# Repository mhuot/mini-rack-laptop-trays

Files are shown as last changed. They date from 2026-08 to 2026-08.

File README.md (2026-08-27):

# Mini-Rack Laptop Trays

1U sliding laptop trays for 10-inch mini racks, with an actively cooled, ducted rear exhaust — designed for a MacBook Pro 14" and a Surface Laptop 13.8" living in a GeeekPi/DeskPi RackMate-style 4U cabinet.

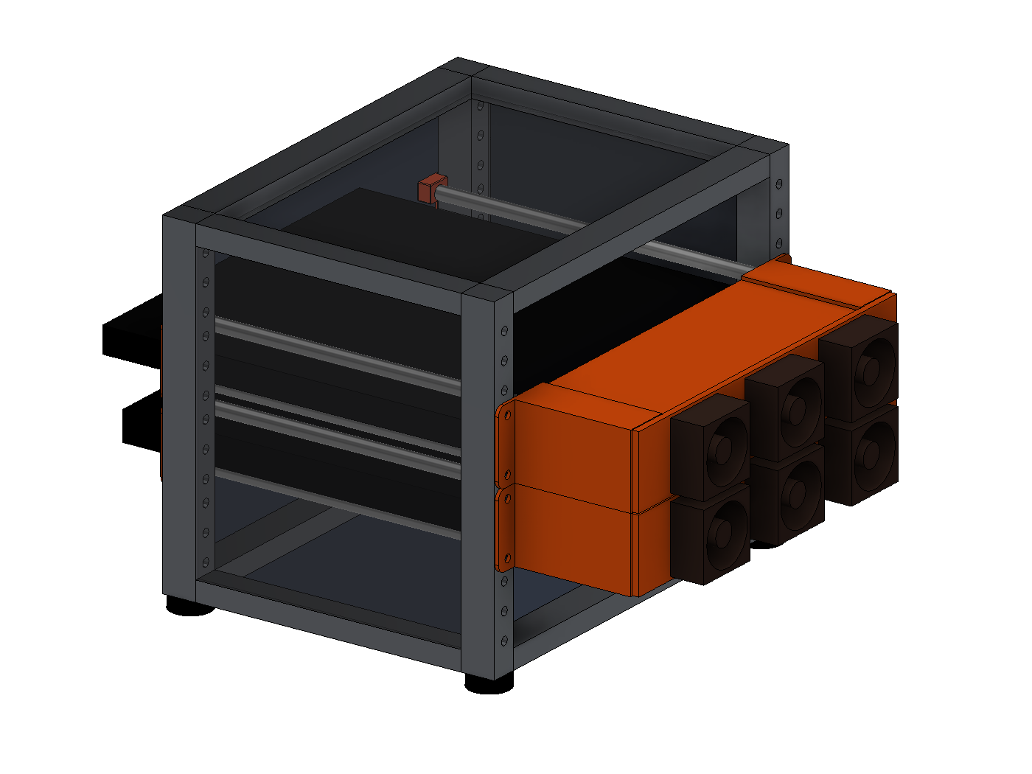
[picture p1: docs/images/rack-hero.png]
Rack mockup with both laptops


Each laptop slides in and out like a drawer on four 8 mm smooth rods, held by 3D-printed ears on the front and rear rack rails. A printed fan plate with three 40 mm Noctua fans bolts onto the rear ears and pulls air across the top and bottom of the laptop, exhausting out the back — all within a single rack unit.

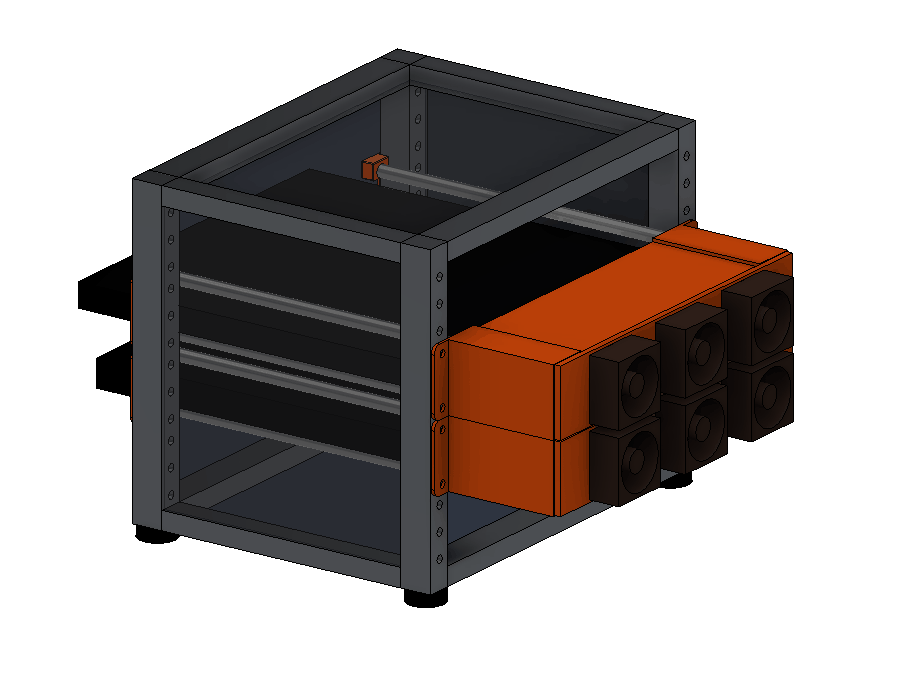
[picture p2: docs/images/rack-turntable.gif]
Turntable spin of the full rack


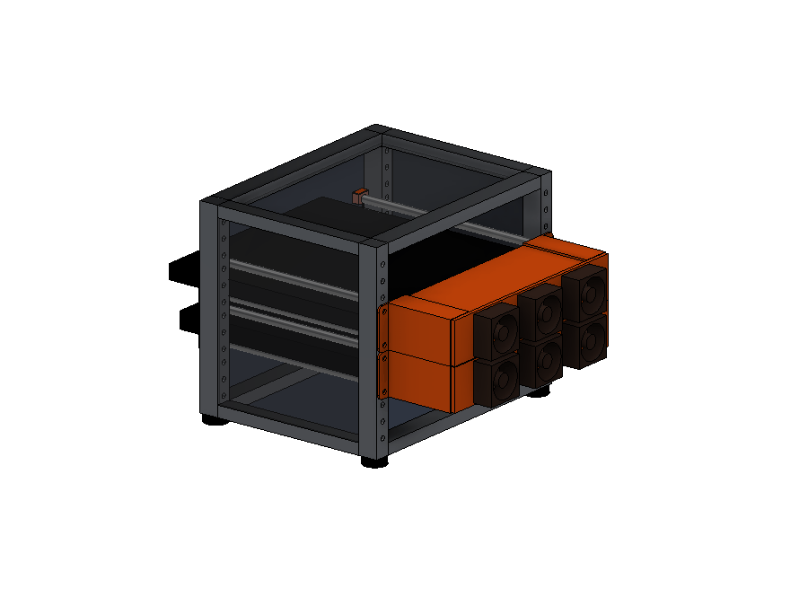
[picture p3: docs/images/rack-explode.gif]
Exploded view of one tray flying apart and back together


Every printed part in the bill of materials is in there, except the fan opening plug — that one only exists if you run two fans instead of three, and this shows three. Fasteners are not modelled.

Want to spin it yourself? **[Open the interactive 3D viewer](https://mhuot.github.io/mini-rack-laptop-trays/)** — full color, drag to orbit, scroll to zoom. GitHub also renders **[docs/rack-mockup.stl](docs/rack-mockup.stl)** with its built-in STL viewer. (Both are visual mockups, not print files — the printable STLs live in [`exports/`](exports/). Printed parts are shown in orange; print in whatever color you like.)

## How it works

| | |
|---|---|
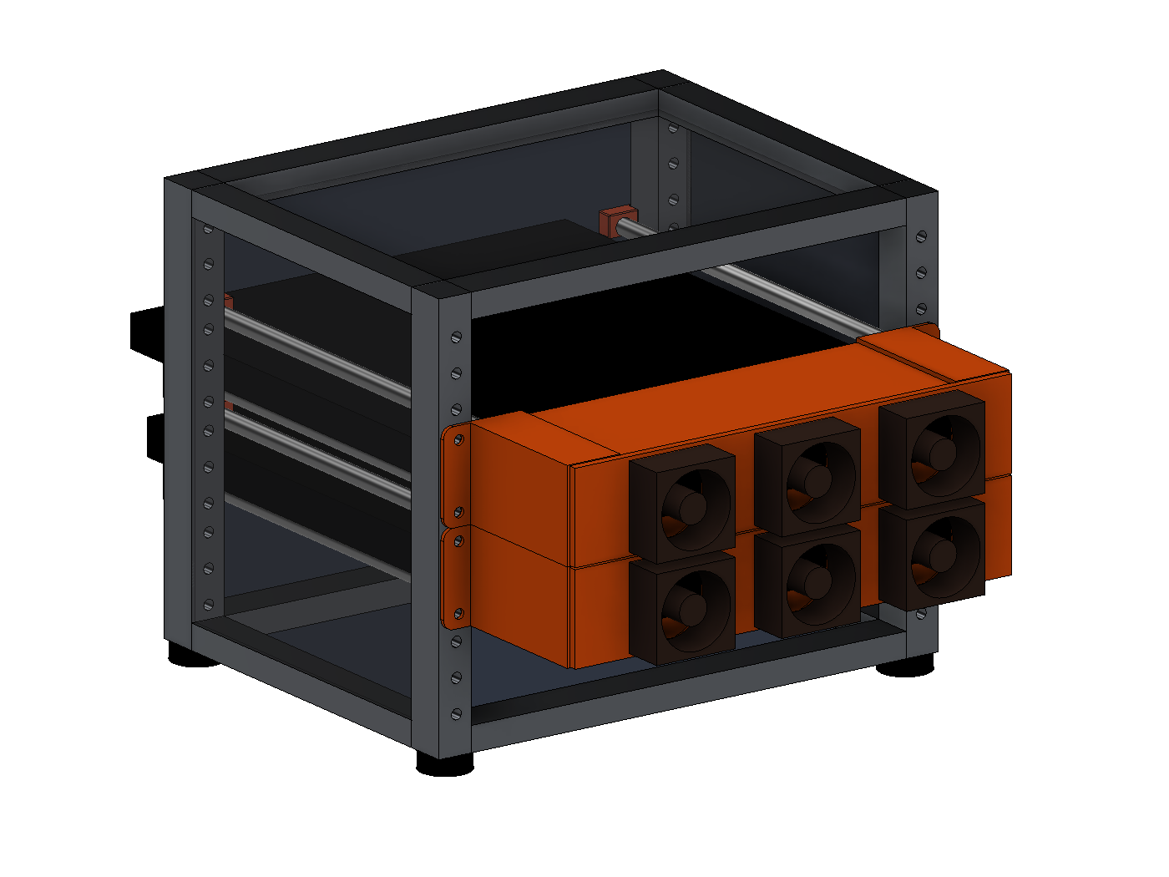
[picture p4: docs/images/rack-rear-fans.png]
Rear fan plates and ducts
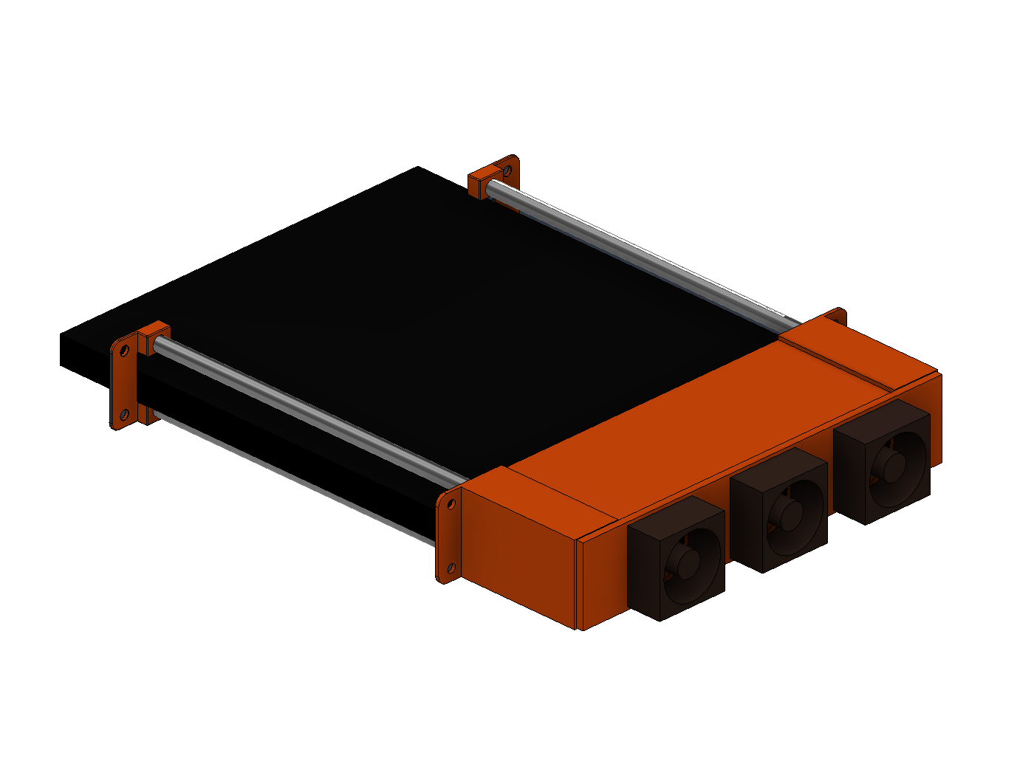
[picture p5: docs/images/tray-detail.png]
Single tray assembly
|  |  |

- **Front and rear ears** print in mirrored pairs and bolt to the rack rails with standard rack screws. Each ear carries two 8 mm smooth-rod positions, spaced to leave a 24 mm gap — the laptop slides between the rod pairs and rests on the lower rods.
- **The rear ears extend 72 mm out the back of the rack**, so the laptop's rear edge sits behind the rear rail and stops against the ears' back plates **65 mm in**. The rod bores run that same 65 mm, so they are blind — the back plate is their floor. The 243 mm rods reach 41 mm in and leave 24 mm of bore empty; a 267 mm rod would bottom out on the plate and be positively located. A MacBook Pro 14 noses 47.6 mm out the front; the Surface Laptop 13.8, 36.0 mm. The 7 mm left between that stop and the fan plate is the duct exit — the gap the air turns through on its way into the fans.
- **The fan plate** screws into heat-set inserts in the rear ears' back plates. Three Noctua NF-A4x20 5V fans (40 mm fits upright inside the 44.45 mm rack unit) exhaust rearward, at x = 0 and ±63.55 — the centroids of three equal zones across the duct, so each draws its own third of it. Two 2.2 mm duct panels close the top and bottom of the rear overhang, and the rear ears carry a 2 mm outboard side wall closing their side windows — so the fans can only draw air from inside the rack, sweeping the lid and the underside of the chassis on the way through.
- **Fan wiring** runs along the rear face of the plate, held clear of the blades by zip ties through the slot pairs between the fan bodies. The outboard pair is strain relief where the bundle leaves for the USB supply. Splices belong outside the rack, near the power source, not pocketed into a 4 mm plate.
- Laptops run clamshell; all cables exit at the front (orient the Surface with its USB-C edge forward).
- The RackMate-style cabinet has closed acrylic sides and top, so the front opening is the only intake: the fans drive true front-to-back flow through the slot, and the hinge-side exhaust is entrained in the same rearward stream. No side baffles needed.

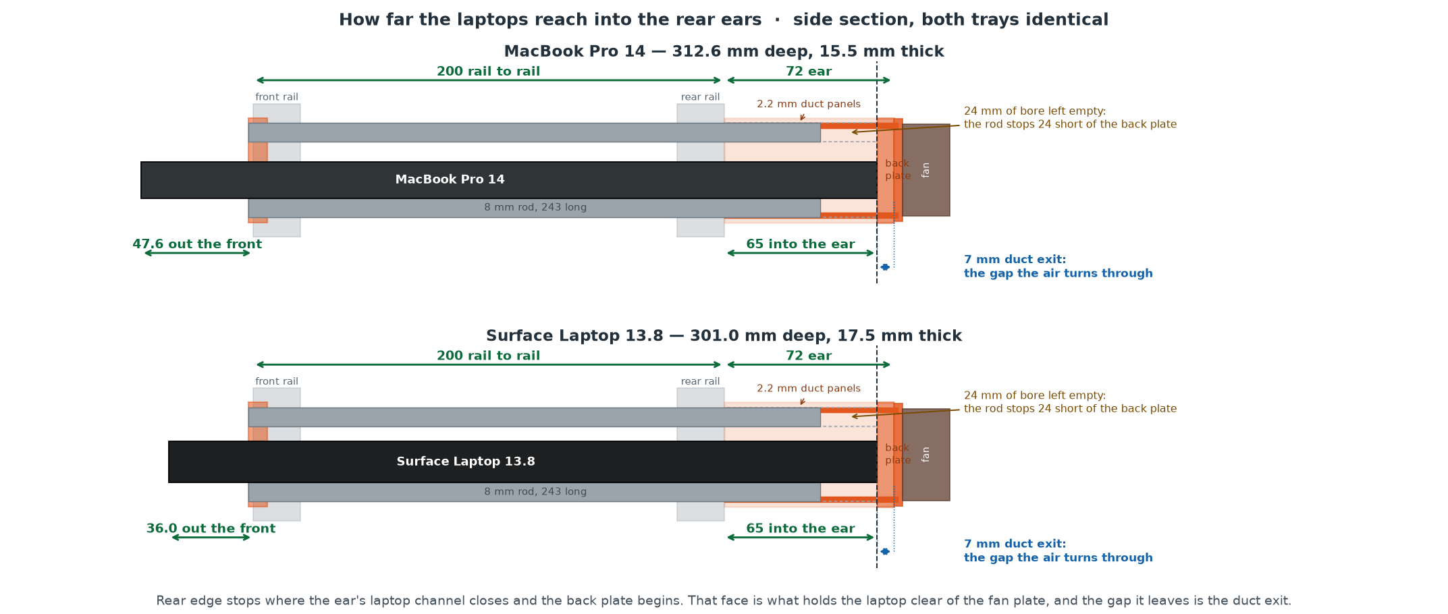
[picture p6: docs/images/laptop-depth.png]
Side section showing how far each laptop reaches into the rear ears


## Compatibility

Designed around a rack with 236.525 mm rail-hole span and 200 mm rail-to-rail depth ([GeeekPi 4U 10-inch cabinet / DeskPi RackMate T0](https://www.amazon.com/dp/B0DPGZPTPP); see the [mini-rack project](https://mini-rack.jeffgeerling.com/) for the ecosystem).

| Laptop | Dimensions (mm) | Fit |
|---|---|---|
| MacBook Pro 14 (M-series) | 312.6 × 221.2 × 15.5 | ✅ designed for |
| Surface Laptop 7th Ed. 13.8" (Intel) | 301 × 220 × 17.5 | ✅ same parts, unchanged |

Anything ≤ 222 mm deep and ≤ ~20 mm thick that can hang its side edges on rods 205.6 mm apart should work.

## Bill of materials (per tray)

**Printed parts** (PETG recommended — parts live next to a warm laptop):

| Part | Qty | Notes |
|---|---|---|
| Front Ear (`exports/front_ear.stl`) | 2 | mirror one in the slicer |
| Rear Ear v2 (`exports/rear_ear_v2.stl`) | 2 | mirror one; bosses take M3 heat-set inserts |
| Rear Fan Plate (`exports/rear_fan_plate.stl`) | 1 | flat 4 mm slab, ~45 min |
| Duct panel (`exports/duct_panel.stl`) | 2 | flat 2.2 mm sheets, 194.4 × 74; slide into the ears' duct rails |
| Fan opening plug (`exports/fan_plug.stl`) | 0–1 | only if starting with two fans — see below |

**Ready-made print plates**, arranged for a 250 × 220 bed and mirrored where needed. Regenerate with `scripts/build_print_plate.py`.

- `exports/print_plate_ears_heatset.3mf` (also `_selftap` / `_nuttrap`) — both rear ears, both front ears, two fan plugs. Print once.
- `exports/print_plate_ducted_fan_plate.3mf` — the one-piece alternative, if you want it instead of the plate-plus-panels.
- `exports/print_plate_duct_panels.3mf` and `exports/print_plate_fan_plate.3mf` — the duct set, split across two plates. This is what you reprint when you change the fan layout.

The duct is two plates rather than one because together the three parts fill the bed corner to corner, which put a panel corner 14 mm from the left edge and 8 mm from the front — and that corner is where first layers fail. Split, each plate centres with at least 20 mm clear on every side, brim included.

The ears also fit a Prusa Mini, so they can go on a second printer while the duct set runs: `exports/print_plate_ears_heatset_mini.3mf`. Neither duct plate can — the panels are 194 mm and the fan plate 222 mm, both past a 180 mm bed. Pass `--bed mini` to the generator for other variants.

The duct is modular on purpose. The two panels slide into duct rails on the rear ears and are trapped by the fan plate, so the duct stays with the rack when the plate comes off. Changing fan count or spacing means reprinting a flat slab in under an hour instead of a six-hour part that is mostly duct wall.

Those duct rails reach 10 mm inboard from each ear, into the dead space above and below the laptop, and carry a 2.4 mm slot between 2 mm walls. That holds a panel over 12 mm of its width rather than the 2 mm a pocket in the ear face managed on its own, and it does it without making the panel any bigger — the rails add material rather than hollowing the ear out, so the rod bores are untouched and the part still prints with no overhangs.

The duct rails only grip 10 mm at each end, though, which left 170 mm of free sheet whose rear edge had nothing holding it against the fan plate. So the plate carries a 2 mm-deep capture groove on each panel line and the panels run 74 mm — 72 of duct plus 2 into the groove. That laps the joint instead of butting it, and pulls the rear edge flat at the same time. Along the panel line each fan opening is only about 8.6 mm wide, so roughly 76% of the panel edge lands in solid groove and the rest opens into a fan opening, which is where the air is going anyway.

Panels are 2.2 mm rather than 2.0 for the same reason a loose hinge rattles: 2.0 in a 2.4 slot leaves 0.4 mm of free play, and a 37 g sheet with that much room next to the fans will buzz. 2.2 is eleven layers at 0.2 mm and halves the gap to a normal sliding fit.

`scripts/check_rear_assembly.py` fits the exported STLs together and checks both of these — every pair intersected exactly for interference, then a flood fill of the air in a cross-section to see whether the duct reaches ambient. It currently reports no interference, and a seal with each panel resting against either wall of its slot.

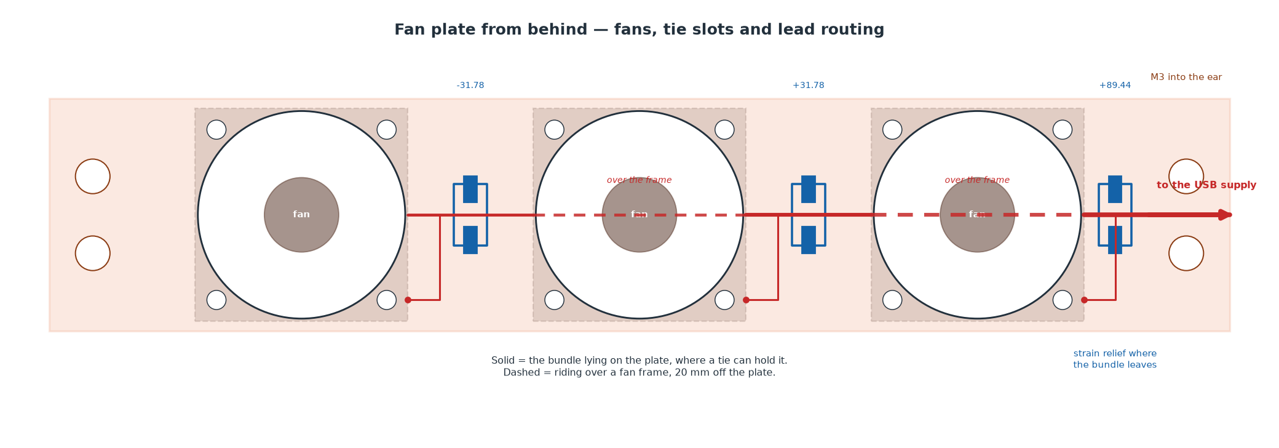
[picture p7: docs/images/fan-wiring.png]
Fan plate from behind, showing the fans, tie slots and lead routing


### Why three fans

Three is where the fan openings stop being the restriction. The duct's own free
area is about 3880 mm² with a MacBook in it and 3498 with the thicker Surface;
three Ø39 openings are 3584 mm². Two would be 2389 — throttling the duct to 62%
and leaving a 47.7 mm fan-free span across the middle of the laptop. Four was
4778, comfortably past the crossover, buying noise rather than air. Three also
draws 0.3 A, so a tray still runs off any USB port.

Positions are the centroids of three equal-width zones, so no part of the duct
is more than 31.8 mm from a fan — against 47.7 mm with two.

### The one-piece alternative

`exports/ducted_fan_plate.stl` is the fan plate with the duct walls grown onto
it: one part instead of three, and no joint to seal because there isn't one.
Its walls are 194.44 mm wide, the same as the separate panels, so they slide
into the same duct rails.

It costs you the thing the modular duct was built for. The fan count is fixed
in the geometry, and the walls print as two 2.2 mm fins standing 72 mm off the
plate, which is slower and more delicate than two flat sheets. Print it
plate-down so the first layer is the full solid rectangle.

No heat-set inserts on hand? Two alternatives, same fan plate and M3 × 8 screws either way:

- **Nut-trap** (`exports/rear_ear_v2_nuttrap.stl`) — a slightly taller rib with side-loading slots that capture standard **M3 hex nuts** (a DIN 562 square nut fits the same slot). Metal threads, unlimited assembly cycles, hardware you already have. The fan plate sits 2 mm further back (~98 mm total behind the rear rail).
- **Self-tap** (`exports/rear_ear_v2_selftap.stl`) — Ø2.5 pilot holes the M3 screws thread directly into the plastic. Simplest, but good for only about a dozen assembly cycles.

The insert version remains the most compact and the nicest to work on.

A note on all three, because it is not obvious from looking at them: the ear prints standing on its rail flange, so the back plate starts as a bridge across the open duct and the insert pocket sits directly above it. Whatever floor is left under a pocket is made of the first bridged layers, with nothing on top to pull them flat — get it too thin and the bottom of the pocket comes out rough. The heat-set pocket is 3.2 mm deep on a 3.8 mm floor; the self-tap and nut-trap variants keep 1.5 mm on a thinner plate.

**Hardware:**

| Item | Qty | Notes |
|---|---|---|
| 8 mm smooth rod, 243 mm | 4 | see [Smooth rods](#smooth-rods) |
| [Noctua NF-A4x20 5V](https://www.amazon.com/Noctua-NF-A4x20-5V-3-Pin-Premium/dp/B072Q3CMRW) | 2–3 | ships with OmniJoin + fan screws |
| [M3 × 3 mm heat-set inserts (short)](https://cnckitchenus.store/products/heat-set-insert-m3-x-3-short-version-100-pieces) | 4 | e.g. CNC Kitchen; Ø4.0 × 3.2 pockets (skip for the self-tap ear variant) |
| M3 × 8 socket-head screws | 4 | |
| M3 hex nuts | 4 | nut-trap ear variant only |
| Rack screws | 8 | per your rack's rail standard |
| Spare USB-A cable to sacrifice | 1 per tray | spliced with the included OmniJoin set — see [Wiring](#wiring-the-fans) |
| Noctua NA-SYC1 chromax Y-cables | optional | [set of three](https://www.amazon.com/Noctua-NA-SYC1-black-NA-SYC1-chromax-Black-y-Cables/dp/B076542HBN) tidies one tray's junction |

## Wiring the fans

The NF-A4x20 5V draws 0.1 A max ([0.5 W, spec](https://www.noctua.at/en/products/nf-a4x20-5v/specifications)), so a full tray of four is 0.4 A worst case — inside the 0.5 A budget of any USB 2.0 port. Both trays on one port is 0.8 A, which wants a USB 3 port (0.9 A) or a 5 V / 1 A phone charger.

The box gives you everything except the USB end: each fan ships with a 30 cm extension and Noctua's OmniJoin splice set (solderless 3M connectors). No USB adapter is included, and **avoid generic "USB fan adapter" cables — most contain a 5 V→12 V boost converter that will kill a 5 V fan.** A 5 V Noctua must never see 12 V.

Per tray:

1. Sacrifice any USB-A cable. Cut off the device end, strip the jacket, keep the **red (+5 V)** and **black (GND)** conductors, and insulate the data pair (green/white) out of the way.
2. Join all three fans' +5 V leads to USB red and all three GND leads to USB black with the OmniJoin connectors (identify the fan leads from the OmniJoin instruction leaflet — Noctua's cables are all-black, the leaflet is the pinout). Leave each fan's tach lead unconnected and insulated; nothing reads it.
3. Route the bundle along the top duct panel, down the inside of the rear post, and zip-tie it with a service loop generous enough that the fan plate can be unscrewed without unplugging anything.
4. Plug in and confirm all four spin before sliding the laptop in.

If you'd rather not splice three joints, two [NA-SYC1 Y-cables](https://www.amazon.com/Noctua-NA-SYC1-black-NA-SYC1-chromax-Black-y-Cables/dp/B076542HBN) merge the three fans to a single 3-pin lead first, leaving one splice to the USB cable. Passive wiring, fine at 5 V.

**Two fans or three?** Rough math says two fans per tray move enough air for typical clamshell loads (~14 °C air rise carrying 40 W); three is what the duct can actually swallow — see [Why three fans](#why-three-fans). The plate has three openings either way, and an empty opening would let the running fans pull backflow, so if you start with two, print a plug and press it into the unused opening from the rear (duct suction seats it tighter). Use the two outer positions and plug the centre. To upgrade later, drive an M3 screw two turns into the plug's center pilot, pull it, and add the third fan — no reprint. The print plates include two plugs.

## Smooth rods

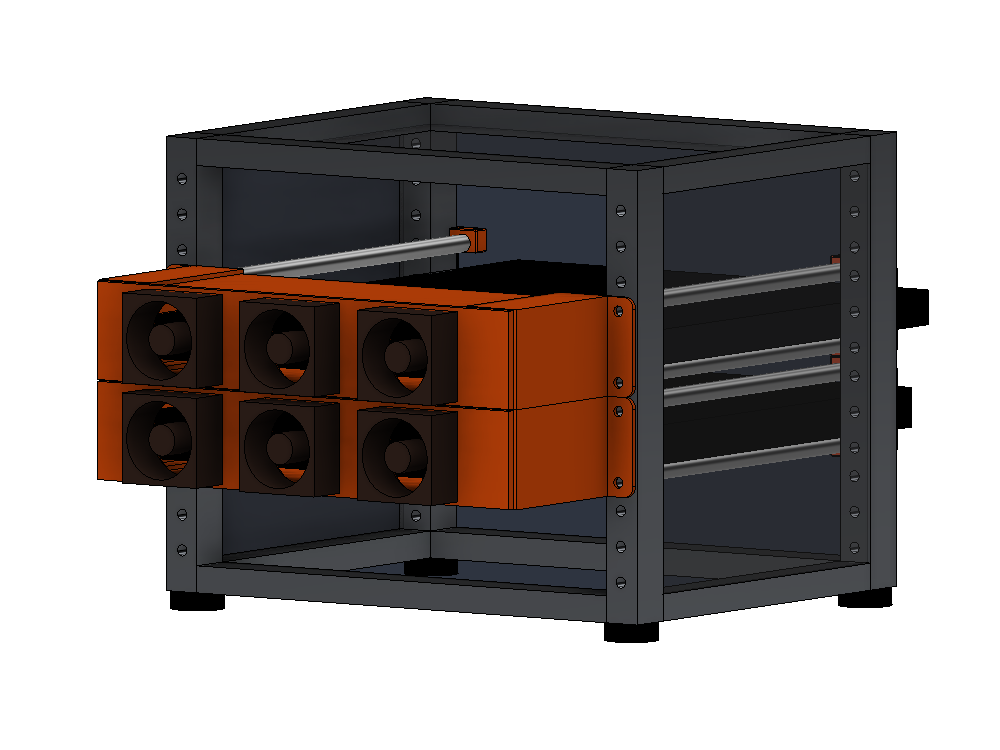
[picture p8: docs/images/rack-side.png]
Side view: rod runs and laptop overhang


Any 8 mm smooth rod works (hardened steel or stainless linear rod is ideal — it's what the renders show). The rods are just long enough to connect the front and rear ears — they do **not** extend past the front:

- **Cut all four rods to 243 mm** (the as-built length). That runs from flush with the front ear's face, through the 200 mm rack, and ~40 mm into the rear ears' bores — plenty of engagement without needing to bottom out against the rear back plates.
- The front ears straddle the front rail: only their thin 2 mm face plate (with the recessed screw heads) sits on the rail's front face, while the rod blocks pass through the rack opening behind it. The front of the rack stays essentially flush — nothing pokes forward but the laptops.
- The laptop's front overhang (MacBook Pro 14: ~45 mm, Surface 13.8: ~33 mm) is cantilevered past the front ears — the chassis is more than stiff enough for this.
- Deburr and lightly chamfer the ends so they slide into the printed bores without shaving them. The 8.0 mm fit is snug — no retention hardware needed, and the fan plate closes off the rear.

## Assembly

1. Print the parts; heat-set the four inserts into the rear ear bosses.
2. Mount front ears to the front rails, rear ears to the rear rails (rear ears point out the back of the rack).
3. Slide the four rods through the front ears into the rear ears' sockets.
4. Screw the fans to the rear face of the fan plate (labels facing back — they exhaust rearward), then drive the M3 screws through the plate's counterbored tabs into the ear inserts.
5. Wire the fans per [Wiring](#wiring-the-fans), confirm they spin, and slide the laptop in, lid closed, cables at the front.

Total stack behind the rear rail is ~96 mm (ears 69 + pads 3 + plate 4 + fans 20) — leave that much clearance behind the rack.

## CAD

Models are built in Fusion 360, driven by the Python scripts in [`scripts/`](scripts/) (run inside Fusion — e.g. via a Fusion MCP add-in, or paste into a Fusion script). Each script is parametric through the constants at the top and regenerates its part from scratch:

- [`build_rear_ear_v2.py`](scripts/build_rear_ear_v2.py) — copies the proven rear ear bodies and adds the insert bosses
- [`export_front_ear.py`](scripts/export_front_ear.py) — exports the front ear with a slicer-friendly tangency relief
- [`build_print_plate.py`](scripts/build_print_plate.py) — assembles the one-tray 3MF print plates from the STLs
- [`build_rear_fan_plate.py`](scripts/build_rear_fan_plate.py) — the fan plate, with the wiring tie slots
- [`build_duct_panel.py`](scripts/build_duct_panel.py) — the duct panels
- [`build_fan_plug.py`](scripts/build_fan_plug.py) — the blanking plug for unused fan openings
- [`build_rack_mockup.py`](scripts/build_rack_mockup.py) — the full-rack mockup used for the renders on this page
- [`add_duct_rails.py`](scripts/add_duct_rails.py) — adds the duct rails to the parametric rear ear
- [`fix_insert_pockets.py`](scripts/fix_insert_pockets.py) — cuts the heat-set pockets as one explicit feature

And three that run locally rather than inside Fusion:

- [`check_rear_assembly.py`](scripts/check_rear_assembly.py) — fits the rear parts together and checks for interference and air leaks
- [`whiten_renders.py`](scripts/whiten_renders.py) — flattens Fusion's viewport gradient to white in the exported renders
- [`check_terminology.py`](scripts/check_terminology.py) — every part has one name; this fails if a retired one creeps back in. Standard library only, so it just runs.

Fusion API note: all API lengths are centimeters; the scripts define `MM = 0.1` and work in millimeters throughout.

Every printable part also ships as standalone CAD in [`cad/`](cad/) — a STEP and a Fusion archive (`.f3d`) per part, current revision, importable into any CAD package. The original parametric ear and reference-body designs live in the Fusion archives (`*.f3d`) at the repo root.

## License

[MIT](LICENSE) — scripts, models, and STLs alike. Attribution appreciated but not required.

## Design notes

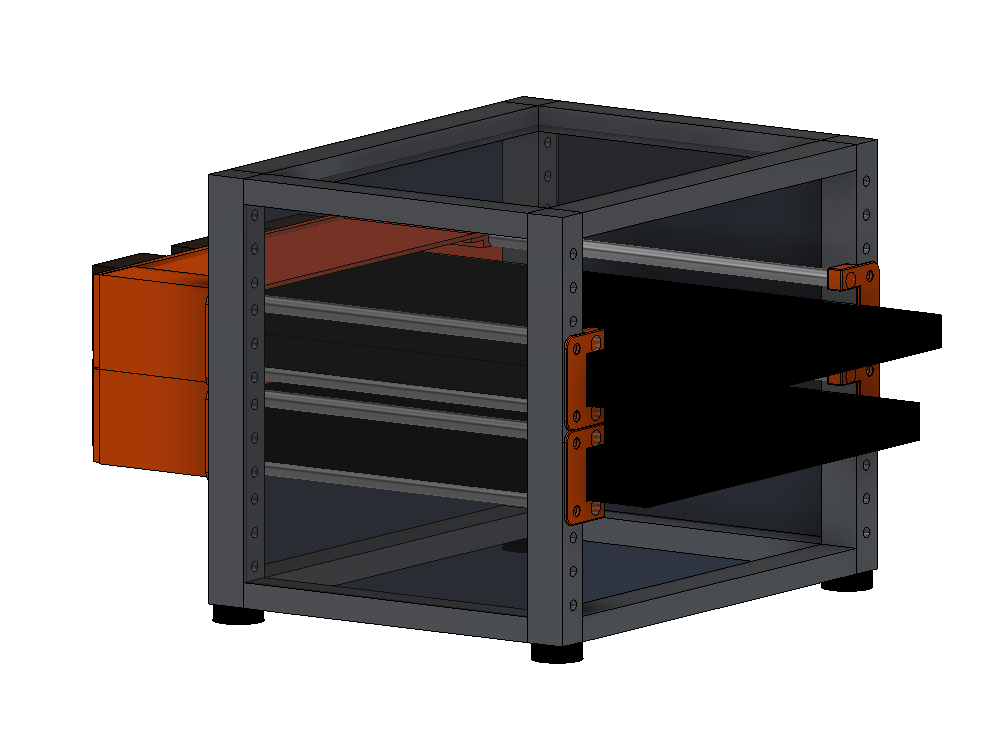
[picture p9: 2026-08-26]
docs/images/rack-front.png

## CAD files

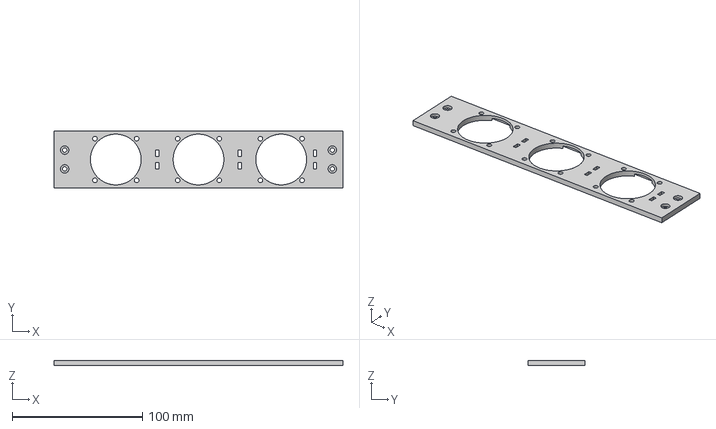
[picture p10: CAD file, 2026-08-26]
cad/rear_fan_plate.step
222.0 x 43.6 x 4.00 mm

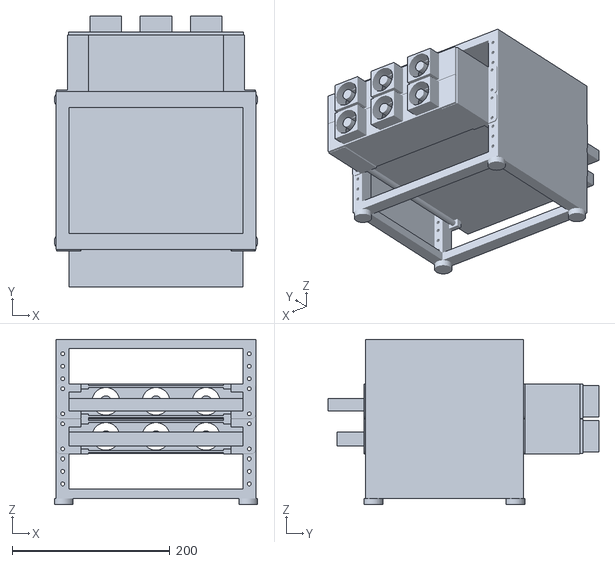
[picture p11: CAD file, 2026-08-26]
docs/rack-mockup.stl
258.0 x 343.6 x 209.8

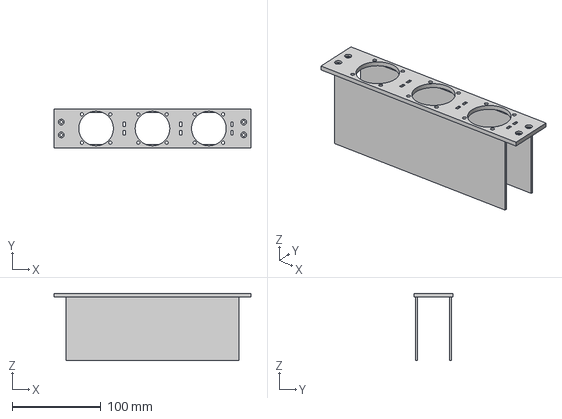
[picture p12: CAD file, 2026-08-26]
cad/ducted_fan_plate.step
222.0 x 43.6 x 76.0 mm

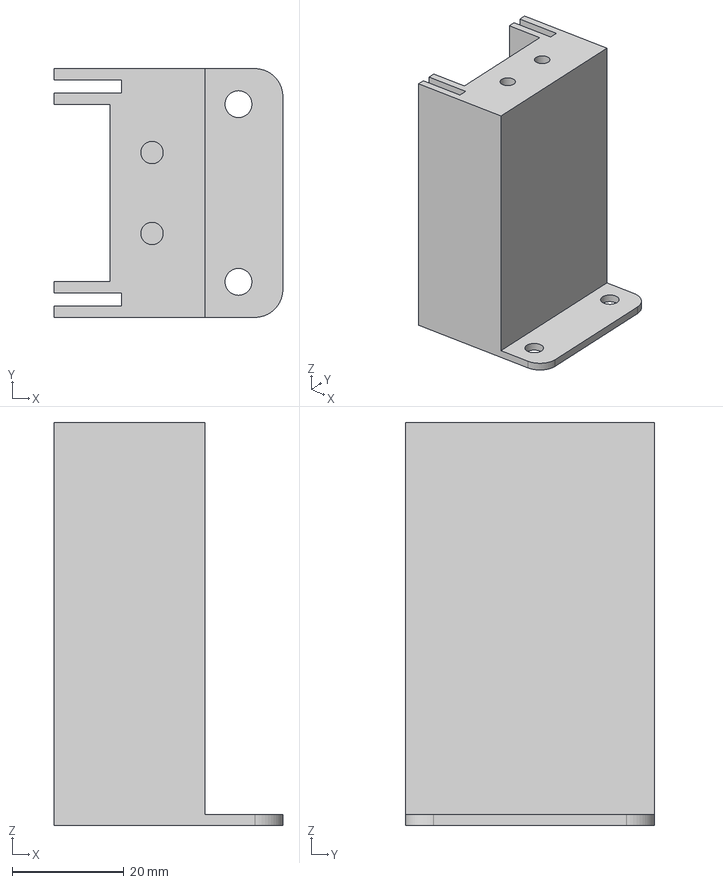
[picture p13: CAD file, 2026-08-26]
cad/rear_ear_v2_heatset.step
40.9 x 44.5 x 72.0 mm

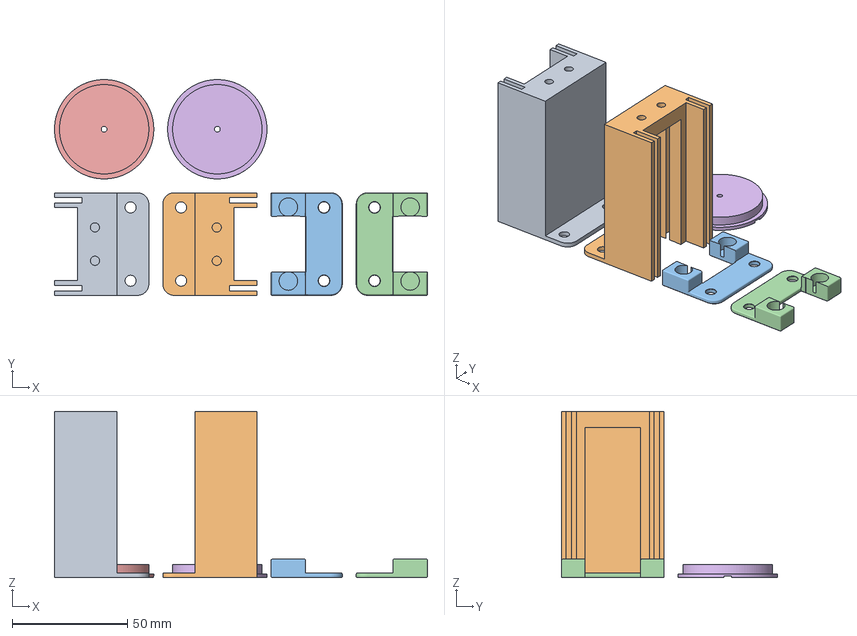
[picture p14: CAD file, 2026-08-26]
exports/print_plate_ears_heatset_mini.3mf
161.5 x 93.4 x 72.0 mm
rear_ear_R
rear_ear_L
front_ear_R
front_ear_L
fan_plug_1
fan_plug_2

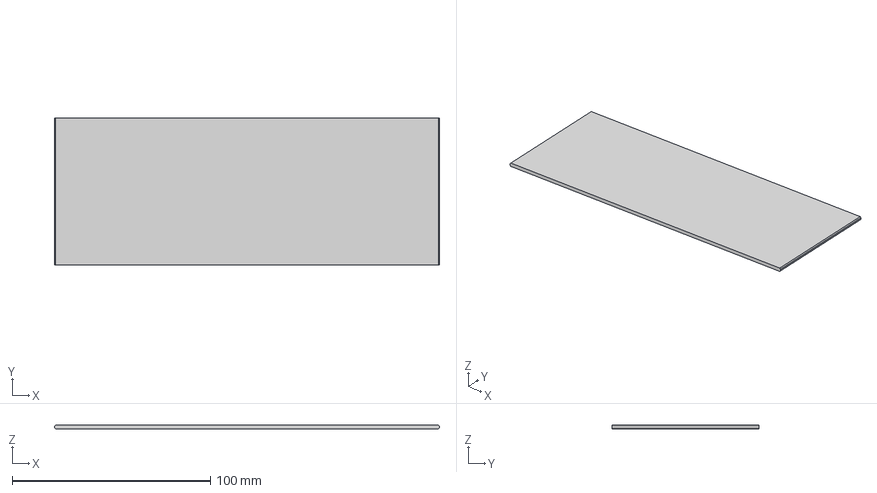
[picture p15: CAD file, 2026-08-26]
cad/duct_panel.step
194.4 x 74.0 x 2.20 mm

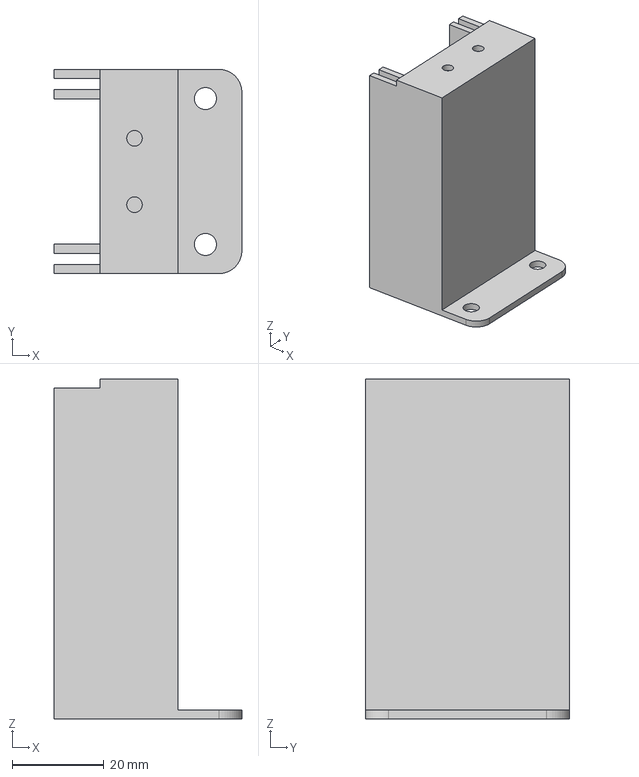
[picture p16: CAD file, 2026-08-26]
cad/rear_ear_v2_nuttrap.step
40.9 x 44.5 x 74.0 mm

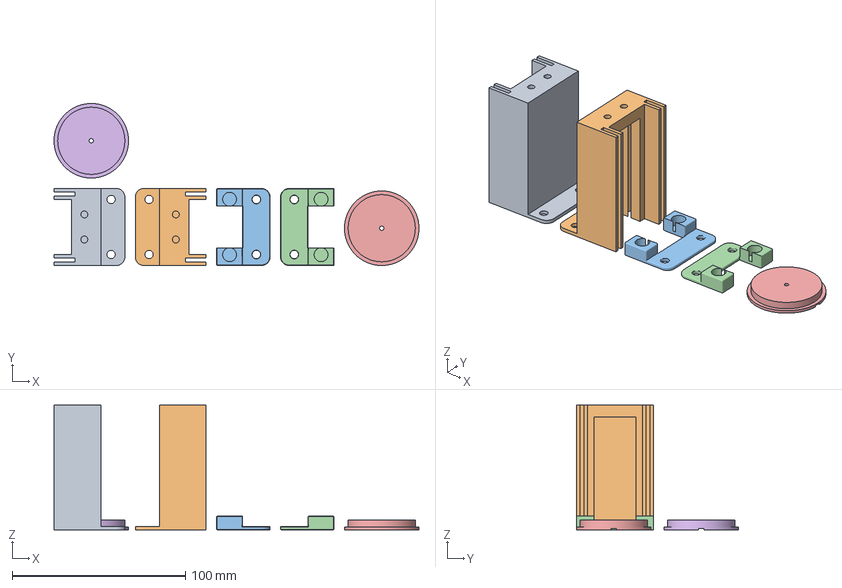
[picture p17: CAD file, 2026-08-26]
exports/print_plate_ears_heatset.3mf
210.5 x 93.4 x 72.0 mm
rear_ear_R
rear_ear_L
front_ear_R
front_ear_L
fan_plug_1
fan_plug_2

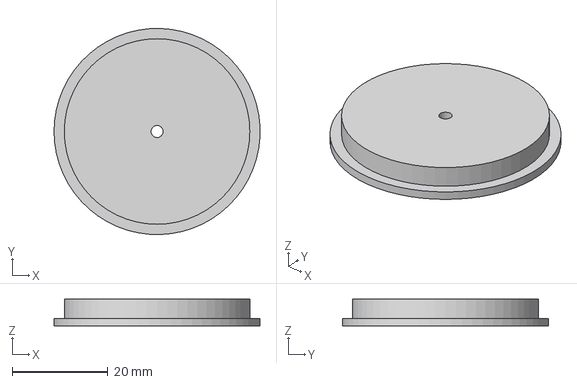
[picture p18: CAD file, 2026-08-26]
cad/fan_plug.step
43.0 x 43.0 x 5.60 mm

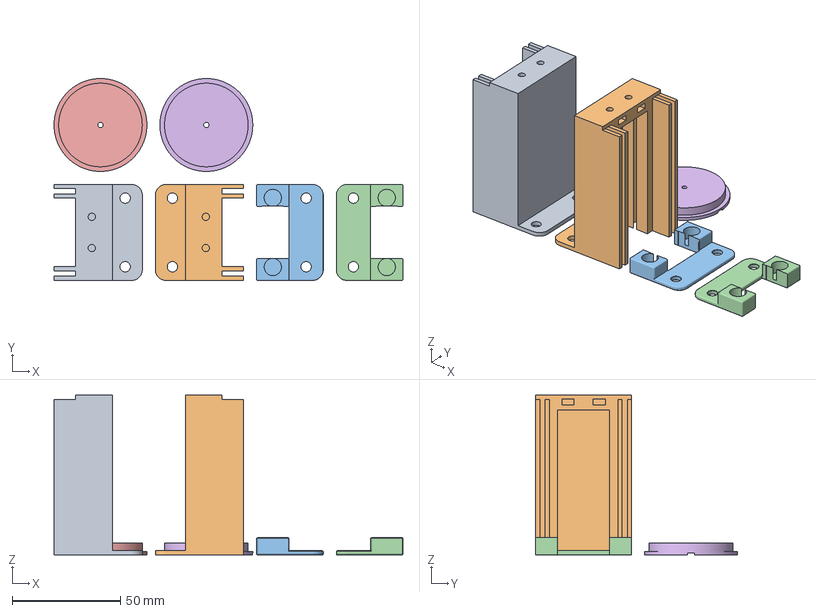
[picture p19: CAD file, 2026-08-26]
exports/print_plate_ears_nuttrap_mini.3mf
161.5 x 93.4 x 74.0 mm
rear_ear_R
rear_ear_L
front_ear_R
front_ear_L
fan_plug_1
fan_plug_2

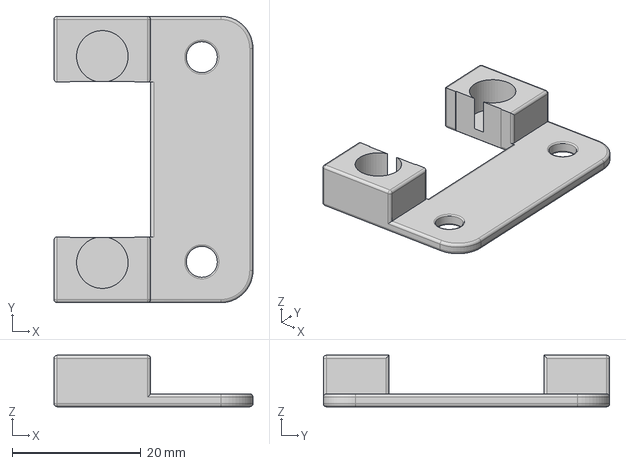
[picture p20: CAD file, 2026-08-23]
cad/front_ear.step
30.9 x 44.5 x 8.00 mm

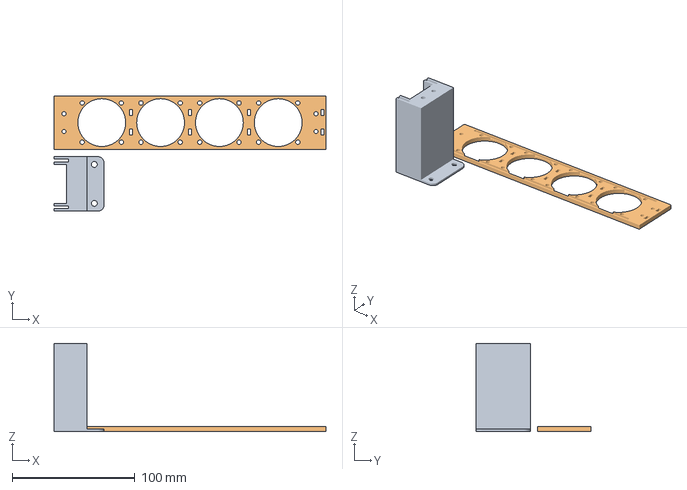
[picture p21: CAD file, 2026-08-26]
exports/print_plate_ear_and_plate.3mf
222.0 x 94.1 x 72.0 mm
rear_ear_relief_fix
rear_fan_plate

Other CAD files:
exports/print_plate_fan_plate.3mf
exports/print_plate_ducted_fan_plate.3mf
exports/print_plate_ears_selftap_mini.3mf
cad/rear_ear_v2_selftap.step
exports/print_plate_ears_selftap.3mf
exports/print_plate_one_rear_ear.3mf
Brackets for Speaker Stand v2.f3d
MacBook Pro Front Ear.f3d
MacBook Pro Rear Ear.f3d
cad/duct_panel.f3d
cad/ducted_fan_plate.f3d
cad/fan_plug.f3d
cad/front_ear.f3d
cad/rear_ear_v2_heatset.f3d
cad/rear_ear_v2_nuttrap.f3d
cad/rear_ear_v2_selftap.f3d
cad/rear_fan_plate.f3d
exports/duct_panel.stl
exports/ducted_fan_plate.stl
exports/fan_plug.stl
exports/front_ear.stl
exports/print_plate_bridge_test.3mf
exports/print_plate_duct_panels.3mf
exports/print_plate_ears_nuttrap.3mf
exports/rear_ear_v2.stl
exports/rear_ear_v2_nuttrap.stl
exports/rear_ear_v2_selftap.stl
exports/rear_fan_plate.stl

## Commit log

2026-08-22 Add existing Fusion archives and rack photos for MacBook Pro 1U tray rework
    Claude-Session: https://claude.ai/code/session_01FucNznPGZfhzUNsFimLYsu
    [Brackets for Speaker Stand v2.f3d, MacBook Pro Front Ear.f3d, MacBook Pro Rear Ear.f3d]
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2026-08-22 Rework fan bar to mount on Rear Ear v2 back-plate bosses
    The rear ears extend 67 mm behind the rear rail, so the bar cannot sit on
    the rail face. v2: 222 mm bar screws into CNC Kitchen M3x3 short heat-set
    inserts in new bosses added to the rear ear back plates; fans nest between
    the plates. Adds build_rear_ear_v2.py (copies proven ear bodies, adds
    bosses via temporary BRep booleans).
    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
2026-08-22 Shift insert bosses clear of rod bores; export v2 STLs
    Boss rows moved from y 14.0/30.45 to 15.0/29.45 so the 9 mm pads no longer
    overhang the 8 mm rod pass-throughs in the back plate. Add high-refinement
    STL exports of Rear Ear v2 and Rear Fan Bar.
    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
    [rear_ear_v2.stl, rear_fan_bar.stl]
2026-08-22 Add integrated duct shell to fan bar to prevent intake short-circuit
    1.8 mm top/bottom panels project 70 mm forward from the bar face, spanning
    between the ear inner faces and stopping 2 mm shy of the rear rail. Forces
    the exhaust fans to draw only from inside the rack, through the channels
    above the lid and under the chassis.
    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
    [rear_fan_bar.stl]
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2026-08-22 Add front ear STL, interactive mockup STL, and turntable GIF
    - exports/front_ear.stl was missing from the BOM's printed parts
    - docs/rack-mockup.stl: whole-assembly mesh, orbitable via GitHub's
    built-in STL viewer (visual mockup, not a print file)
    - docs/images/rack-turntable.gif: 36-frame color turntable in the README
    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
    [front_ear.stl, rack-mockup.stl]
2026-08-22 Add rod-length guide, self-tap ear variant, orange prints, and 3D viewer site
    - README: smooth-rod section (275 mm upper / 320 mm lower so the lower pair
    supports the laptop's front overhang; front ears sit fully proud of the
    front rail) with the side view illustrating the runs
    - exports/rear_ear_v2_selftap.stl: no-insert variant with 2.5 mm pilot
    holes for thread-forming M3s; documented in the build script
    - Mockup: printed parts now render in orange for contrast; lower rods
    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
    [rack-mockup.stl, rear_ear_v2_selftap.stl]
2026-08-22 Correct rod geometry: rods span ears only, all four cut to 275 mm
    Rods do not extend past the front ears; the laptop's front overhang is
    cantilevered. Reverts the extended-lower-rod advice in the README and the
    mockup, and regenerates renders, turntable GIF, mockup STL, and GLB.
    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
    [rack-mockup.stl]
2026-08-22 Fix viewer colors: Prusa orange prints, correct groups, linear-space GLB
    - Printed parts now Prusament Prusa Orange (#F75403) in renders and GLB
    - GLB part classification is substring-based, fixing rods and the
    duplicate-named fans that rendered as printed parts in the viewer
    - Convert palette sRGB -> linear for glTF baseColorFactor (colors were
    washed out: gray laptops, pale prints)
    - Move GIF/GLB assembly into scripts/build_web_assets.py
    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
2026-08-22 Correct rod length to as-built 243 mm; add front-ear mounting detail
    Rods run from flush with the front ear face ~35 mm into the rear ear
    bores; they don't reach the back plates. Regenerated renders, GIF, GLB,
    and mockup STL with the corrected rod geometry.
    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
    [rack-mockup.stl]
2026-08-22 Fix front ear mounting: 2 mm plate on rail face, blocks behind the rail
    The ear straddles the front rail rather than sitting proud of it: only
    the thin face plate shows at the front (matching the as-built photos).
    Rail plates modeled thin and outboard of the ear blocks; rods run z=-2
    to 241. Regenerated renders, GIF, GLB, and mockup STL.
    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
    [rack-mockup.stl]
2026-08-22 Seal plate-to-bar gap with full-height boss rib on Rear Ear v2
    The fan bar previously stood off the back plates on two round pads,
    leaving a 3 mm side slot that let the duct draw leak air around the
    plates. A 9 mm wide full-height rib now carries both insert pockets and
    closes the slot; same 3 mm standoff, same bar and screws. Both ear STL
    variants re-exported; renders, GIF, GLB, and mockup STL regenerated.
    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
    [rack-mockup.stl, rear_ear_v2.stl, rear_ear_v2_selftap.stl]
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2026-08-22 Fill frame corner voids left by the thin-rail change
    Thinning the post mounting faces to 3 mm left 17 mm hollow joints where
    the 20 mm-deep top/bottom rails met the posts. Corner blocks now fill
    the joint bands, matching the full-depth corner extrusions of the real
    rack. Regenerated renders, GIF, GLB, and mockup STL.
    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
    [rack-mockup.stl]
2026-08-22 Restore full-depth corner posts; acrylic now spans rail to rail
    The thin-rail detour was unnecessary: the front ears' plates sit in
    front of the rail face and their rod blocks pass through the opening
    inboard of the posts, so nothing needs clearance behind the corners.
    Full-height, full-depth posts return (as on the real T0), the corner
    block patch is gone, and the side acrylic butts the posts with no gap.
    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
    [rack-mockup.stl]
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2026-08-22 Add nut-trap rear ear variant (M3 hex nuts, no inserts)
    Third boss option: a 5 mm rib with side-loading slots gripping the 5.5 mm
    across-flats of standard M3 hex nuts (DIN 562 square nuts fit too), plus
    a screw relief bore so the same M3x8 screws work without bottoming out
    or reaching the laptop-facing plate. Fan bar sits 2 mm further back.
    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
    [rear_ear_v2_nuttrap.stl]
2026-08-22 Close the rear ears' open side windows with an outboard wall
    Slicing the ear body showed the outboard side is open behind the 2 mm
    mounting flange — a ~65 x 44 mm window per side exposing the duct
    interior to outside air (a 15-20% fan short-circuit, spotted by Mike in
    the viewer). All three ear variants now carry a 2 mm side wall attached
    along the inboard structure, with a 0.6 mm relief step in the laptop
    band. Interior edge-sweep path unchanged. README claim corrected;
    renders, GIF, GLB, mockup STL, and all ear STLs regenerated.
    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
    [rack-mockup.stl, rear_ear_v2.stl, rear_ear_v2_nuttrap.stl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]
2026-08-22 Add one-tray print plates (3MF) for PrusaSlicer
    scripts/build_print_plate.py assembles the five printed parts — mirrored
    ear pairs, fan bar flipped duct-up — onto a 250 x 210 bed and writes a
    vanilla 3MF per rear-ear variant. Round-trip verified with trimesh.
    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
2026-08-22 Fix slicer open-edge warnings: relieve rod-bore tangency in the ears
    The stock ear design has its 8 mm rod bores exactly tangent to the
    laptop slot faces (center 6.22/38.23 + r4 = faces at 10.22/34.23),
    producing edges shared by four faces that PrusaSlicer reports as open.
    A 0.12 mm relief on the slot faces in the rod band makes the
    intersections transversal — the laptop rides on the rods either way.
    Applied to all rear ear variants and to a new front ear export script;
    all five STLs now verify watertight with zero non-manifold edges.
    Print plates regenerated.
    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
    [front_ear.stl, rear_ear_v2.stl, rear_ear_v2_nuttrap.stl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]
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2026-08-23 Add per-part STEP and F3D exports in cad/
    Every printable part (front ear, three rear ear variants, fan bar) now
    ships as standalone CAD at current revision, importable into Fusion or
    any other package — previously the new parts existed only as build
    scripts and STLs.
    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
    [front_ear.f3d, front_ear.step, rear_ear_v2_heatset.f3d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]
2026-08-23 Flatten rear ear back to a single landing level; wall meets pad plane
    Responding to design review: the 9 mm boss rib (a legacy of the round
    insert pads) and the side wall stopping at the plate face left stepped
    levels and a pointless notch at the rear. The boss pad now spans the
    full plate face and the side wall runs to the pad plane, so the fan bar
    lands on one flat surface. The laptop clearance groove remains (the
    laptop edge sits 0.28 mm proud of the ear body face). Applied in the
    parametric cloud doc and synced to the scripts; all STLs, CAD files,
    plates, renders, GIF, GLB regenerated; meshes verify manifold.
    Claude-Session: https:/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
    [rack-mockup.stl, rear_ear_v2.stl, rear_ear_v2_heatset.f3d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]
2026-08-23 Rewrite Pages site as a project promo in Mike's voice
    Landing page now tells the short version of the story, keeps the 3D
    viewer as centerpiece, shows two renders, and points at the files.
    Voice per write-like-mike. Honest about the untested thermals.
    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
2026-08-23 Add fan blanking plugs and the two-fans-or-four guidance
    New printed part: a press-fit plug for unused fan bar openings, so a
    tray can start with two fans without the empty holes short-circuiting
    the duct (backflow). Flange seats on the bar's rear face and suction
    holds it; an M3 screw in the center pilot pulls it for the upgrade to
    four. Plates now include two plugs; README and the promo page carry the
    airflow math and the upgrade path. Also linked the CNC Kitchen inserts
    on the promo page.
    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
    [fan_plug.f3d, fan_plug.step, fan_plug.stl]
2026-08-23 Rebuild fan plug parametrically with a named timeline
    Project rule going forward: everything Claude builds via the Fusion MCP
    uses real sketches and features with named timeline items so a human
    can edit it. Plug rebuilt accordingly (Flange, Press-fit body, Puller
    pilot), saved to the cloud as 'Fan Bar Blanking Plug', and re-exported;
    plates regenerated.
    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
    [fan_plug.f3d, fan_plug.step, fan_plug.stl]
2026-08-23 Add precise fan wiring guidance
    Verified specs: NF-A4x20 5V draws 0.1 A max, ships with OmniJoin splice
    set and 30 cm extension but no USB adapter. README gains a Wiring
    section with the current budget (0.4 A/tray on USB 2.0, 0.8 A for both
    trays wants USB 3 or a 1 A charger), the OmniJoin-to-sacrificed-USB-cable
    procedure, the 12 V boost-adapter warning, routing advice, and optional
    NA-SYC1 Y-cables. Promo page wiring line corrected to match.
    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
2026-08-23 Extend fan bar duct panels 2 mm to meet the rear rail
    The duct stopped 2 mm shy of the rack, leaving a visible gap at the back.
    Extending the panels to 72 mm closes it without touching the rear ear.
    The panels sit inboard of both the ear flanges and the rack posts, so they
    project into the open 1U slot with nothing to foul.
    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
    [rear_fan_bar.f3d, rear_fan_bar.step, rear_fan_bar.stl]
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2026-08-23 Split the duct off the fan bar into a modular three-part rear assembly
    The fan bar was one 76 mm-tall part that took nearly four hours, most of
    it duct wall, so every change to the fan layout meant reprinting the
    airflow structure too. Now:
    - the fan plate is a flat 4 mm slab with zip-tie slots for the fan wiring
    - two 2 mm duct panels print flat and slide into new capture grooves in
    the rear ears, so the duct stays with the rack when the plate comes off
    - print plates split into a print-once brackets set and a duct set, with
    overlap and bed-bounds checks in the generator
    Also fixes a latent NameError in build_rear_ear_v2.py: SIDE_WALL_Z1 was
    referenced after being removed from the con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
    [duct_panel.f3d, duct_panel.step, duct_panel.stl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]
2026-08-23 Make the plate generator bed-aware and add Prusa Mini brackets plates
    Replaces hardcoded part coordinates with a row packer, so a target bed is
    a parameter rather than a layout rewrite. Adds --bed (coreone, mini) and
    --set. The brackets fit a Mini's 180x180 with room to spare; the duct set
    does not, and now says which part is too big rather than failing bare.
    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
    [print_plate_brackets_heatset_mini.3mf, print_plate_brackets_nuttrap_mini.3mf, print_plate_brackets_selftap_mini.3mf]
2026-08-23 Tighten packer margins so the Core One duct set places again
    The 10 mm edge margin left the fan plate 4 mm short of fitting after the
    third row, which broke duct plate generation in the previous commit.
    8 mm edges and 6 mm gaps place every set on both beds.
    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
    [print_plate_brackets_heatset.3mf, print_plate_brackets_heatset_mini.3mf, print_plate_brackets_nuttrap.3mf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]
2026-08-24 Centre print plate layouts away from the bed corner
    Parts were packed from the origin with an 8 mm margin, which put the
    first object in the front-left corner -- the worst-adhering region of
    this bed, where a brim and first layer failed. The packer now centres
    the finished arrangement, so a set with spare room sits in the middle.
    The brackets plate moves from 8 mm off both edges to 30 mm in X and
    63 mm in Y; plates that genuinely fill the bed are unaffected.
    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
    [print_plate_brackets_heatset.3mf, print_plate_brackets_heatset_mini.3mf, print_plate_brackets_nuttrap.3mf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]
2026-08-24 Capture the duct panels on rails instead of a bare groove
    The 2 mm pocket in the ear's inner face held each panel over only 2 mm of
    its width and left a 0.4 mm lip at the 1U edge. Rather than cut deeper into
    the ear -- which runs at the rod bores and would have forced the panel out
    to 198.44 mm, scrapping the two already printed -- add material inboard.
    A rail now projects 10 mm from each ear face into the dead space above and
    below the laptop and carries the slot with it, so the panel is held over
    12 mm at the same 194.44 x 72 x 2.0 mm size. Walls are 2 mm to match the
    rest of the design and the slot opens to 2.4 mm, giving 0.2 mm of slip per
    face. The grooves move 1.6 mm inward to make ro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
2026-08-24 Give the insert pockets a floor thick enough to bridge onto
    The ear prints standing on its rail flange, so the back plate starts as a
    bridge across the open duct and each insert pocket sits directly above it.
    Whatever floor is left under a pocket is therefore the first bridged layers,
    with nothing above to pull them flat -- which is why the bottom of the
    heat-set pocket came out rough.
    The parametric document cut the pockets with a symmetric extent sketched on
    the plate face, so it reached 3.2 mm down into the plate as well as up
    through the pad and left only 0.80 mm of floor. Those legacy features also
    depended on a chain of projected edges that broke as soon as the extent
    changed, so the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
2026-08-24 Re-export ears and plates with the corrected insert pockets
    Floors are now 3.80 mm heat-set, 1.50 mm self-tap, 1.50 mm nut-trap. All
    three STLs re-audit watertight with zero open edges and every plate still
    places on both beds.
    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
    [print_plate_brackets_heatset.3mf, print_plate_brackets_heatset_mini.3mf, print_plate_brackets_nuttrap.3mf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]
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2026-08-24 Size the capture groove to the rail slot, and deepen it to 2 mm
    Two problems with the 1 mm version, both found by checking the fit rather
    than the depth.
    The groove was sized to the panel (2.2 for a 2.0 panel) while the ear rail
    is 2.4. The panel therefore has 0.4 mm of play in the rail and gravity rests
    it on the rail's lower wall, 0.10 mm outside what the groove would accept --
    so the plate would have jammed on the panel edge instead of seating on the
    pads. The groove is now the rail slot continued: same bands, same width.
    Depth goes 1.0 -> 2.0 in the 4 mm plate, and the panels 73 -> 74, which
    doubles the lap and leaves room for panel length and straightness error.
    This puts the groove'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
    [duct_panel.stl, print_plate_duct.3mf, rear_fan_bar.stl]
2026-08-24 Add a fit and leak check for the assembled rear end
    Answers two questions against the exported STLs rather than by eye.
    Interference: every pair of parts is intersected exactly, so an overlap
    shows up as a positive volume instead of as a surprise on the bed.
    Sealing: a cross-section is taken by casting one ray along +x per scan line,
    which makes the x extents exact and leaves only y sampled, then the air in
    that section is flood-filled from inside the duct. Between z~10 and z~60 the
    parts are prismatic, so a section there holds for the whole stretch.
    Current result: no interference, and the duct seals with each panel resting
    against either wall of its rail slot. It leaks only with a panel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
2026-08-24 Take the rattle out of the duct panels: 2.0 -> 2.2 mm
    The rail slot is 2.4, so a 2.0 panel had 0.4 mm of free play. That is an
    impacting gap, not a resonance problem: a 37 g sheet with that much room
    next to four fans will buzz whatever its natural frequency is. For the
    record it is 43 Hz on the free 171 mm span, with mode 2 at 171 Hz sitting
    near the second rotor harmonic of a 4500 rpm NF-A4x20.
    2.2 mm is 11 layers at 0.2 and halves the gap to 0.2 mm total, which is a
    textbook sliding fit rather than a loose one, and stiffens the panel by a
    third on the way past.
    Re-checked with check_rear_assembly.py: still no interference, still sealed
    with the panel against either wall, and the leak th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
    [duct_panel.stl, print_plate_duct.3mf]
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2026-08-25 Build the mockup from the real ear, and stop mis-colouring the duct
    The mockup copied the original rear ear and bolted approximations of the
    boss pad, side wall and reliefs on as boxes. That drifted: it had no duct
    capture rails and none of the pocket work. It now takes the v2 parametric
    body, which already carries all of it, and the box patches are gone.
    Document lookup goes exact-first on the way past, because "MacBook Pro Rear
    Ear" is a prefix of "MacBook Pro Rear Ear v2 Parametric" and a plain
    startswith could silently pick the wrong one with both open.
    Two colouring traps, both from names: the duct panels are printed parts but
    "panel" matched the smoked-acrylic rule, and the fan plate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
2026-08-25 Regenerate the docs renders and bring the writing up to date
    Every image, the turntable, the GLB and the mockup STL were from before the
    capture rails, the pocket fix, the fan plate groove and the 2.2 mm panels.
    All rebuilt from the current parts, on white, with the tray detail shot now
    rendered with the other tray hidden so it actually shows one tray.
    Text catches up too: 2.2 mm panels, the 74 mm length and what the extra 2 mm
    is for, the split duct plates, and the assembly checker. The site's filament
    estimate is now measured rather than guessed, at 165 g per tray.
    Claude-Session: https://claude.ai/code/session_01FucNznPGZfhzUNsFimLYs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
    [rack-mockup.stl]
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2026-08-25 Fix the laptop relief: a MacBook did not fit between the side walls
    The ear carries a 2 mm outboard side wall so the fans cannot draw leak air
    around the ear's open side, and the laptop's edge passes through it via a
    0.65 mm relief. In the parametric document those happen in the wrong order:
    the relief is cut at timeline item 12 and the side wall is joined at item 18,
    which fills it straight back in.
    That left 220.64 mm clear between the side walls. A MacBook Pro 14 is
    221.20 mm wide, so it was 0.56 mm too much and would not have gone in.
    Re-cutting the relief at the end of the timeline restores 221.94 mm, which
    clears by 0.74. The self-tap and nut-trap variants come from
    build_rear_ear_v2.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
2026-08-25 Re-export the ear and regenerate every doc asset
    Rear ear re-exports watertight at 221.94 mm clear, all six bracket plates
    regenerated, and check_rear_assembly.py still reports no interference and a
    sealed duct. Laptop against ear is down to 1.6 mm3, which is the tangent
    line where it rests on the channel floor: 0.02 mm of lift clears it.
    Renders, turntable, explode and GLB all rebuilt with the corrected ear and
    laptop depth, and the new side-section diagram added.
    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
    [print_plate_brackets_heatset.3mf, print_plate_brackets_heatset_mini.3mf, print_plate_brackets_nuttrap.3mf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]
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2026-08-26 Keep the names settled: CLAUDE.md plus a terminology check
    The rename pass fixes the drift that exists. This is what stops it
    coming back.
    CLAUDE.md is loaded automatically by Claude Code, so every future agent
    gets the canonical terms before it writes anything: ear, fan plate,
    rack rail vs duct rail, fan opening. It also records the two places a
    retired word stays on purpose, so nobody "fixes" the gloss in
    index.html or renames the legacy Fusion document out from under
    build_rack_mockup.py.
    Documentation alone would decay, so scripts/check_terminology.py makes
    it verifiable -- it greps for the retired names and exits nonzero on a
    hit, with both exceptions in an ALLOWED list that requires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
2026-08-26 Close three gaps in the terminology check
    The checker missed the underscore form. "\bfan bars?\b" needs a space and
    "rear_fan_bar" needs the prefix, so a bare "fan_bar" matched nothing -- and
    one was sitting in build_web_assets.py, in a branch left dead when the body
    was renamed to fan plate. The rule is now "fan_bar", which covers both, and
    the dead branch is gone. That is the checker earning its keep on its first
    run against a file the rename pass had missed.
    "bracket" had legitimate uses that would have tripped it -- square, curly,
    angle, and bracket notation -- which would have pushed punctuation into
    ALLOWED and diluted it. They are excluded in the pattern instead, so ALLOWED
    stays for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
2026-08-26 Three fan openings everywhere, and a one-piece ducted alternative
    Four openings were past the point where they help. The duct's own free area
    is about 3880 mm2 with a MacBook in it and 3498 with the thicker Surface;
    four Ø39 openings are 4778, so the duct was the restriction and the fourth
    fan bought noise rather than air. Three are 3584 -- the crossover. Two would
    be 2389, throttling the duct to 62% and leaving a 47.7 mm fan-free span
    across the middle of the laptop.
    So three, at x = 0 and +/-63.55: the centroids of three equal zones across
    the duct, so each fan draws its own third and nothing is more than 31.8 mm
    from one. Three also draw 0.3 A, still any USB port.
    Fewer openings help t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
    [ducted_fan_plate.stl, fan_plug.f3d, fan_plug.step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]
2026-08-26 Regenerate the STEP and F3D files, and add a script that does it
    Everything in cad/ except the front ear and the fan plug predated this
    session's changes: three openings on the fan plate, the duct rails and
    pocket and relief fixes on the ears, 74 x 2.2 on the duct panel. The new
    ducted fan plate had none at all. A stale F3D is worse than a missing one,
    because it opens fine and shows the wrong geometry.
    export_active_cad.py exports whatever the active document holds, so the CAD
    beside a part is regenerated the same way its STL is instead of quietly
    ageing.
    One trap, hit while doing this and now written down in CLAUDE.md: the
    heat-set ear does not come from build_rear_ear_v2.py. That script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
    [duct_panel.f3d, duct_panel.step, ducted_fan_plate.f3d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]
2026-08-26 One tie pair per fan, and a diagram of how the leads actually run
    Six tie pairs existed to let a tie strap a plug into any opening. Dropping
    that requirement puts them where the wiring wants them instead: one in each
    clear span between fan bodies, plus one outboard at each end. Four pairs,
    and the two inner ones still flank the centre opening symmetrically, so a
    plug there can still be strapped if wanted.
    The loop tightens from 16 mm to 9.5 mm (y 17.5/27.0). A three-wire
    NF-A4x20 lead is about 3 mm across; 16 mm let it wander before the tie
    touched it. Both rows still clear the fan screw holes at y 6.225/38.225.
    The orientation was already right and stays: the pair straddles the lead in
    y,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
    [ducted_fan_plate.f3d, ducted_fan_plate.step, ducted_fan_plate.stl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]
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
